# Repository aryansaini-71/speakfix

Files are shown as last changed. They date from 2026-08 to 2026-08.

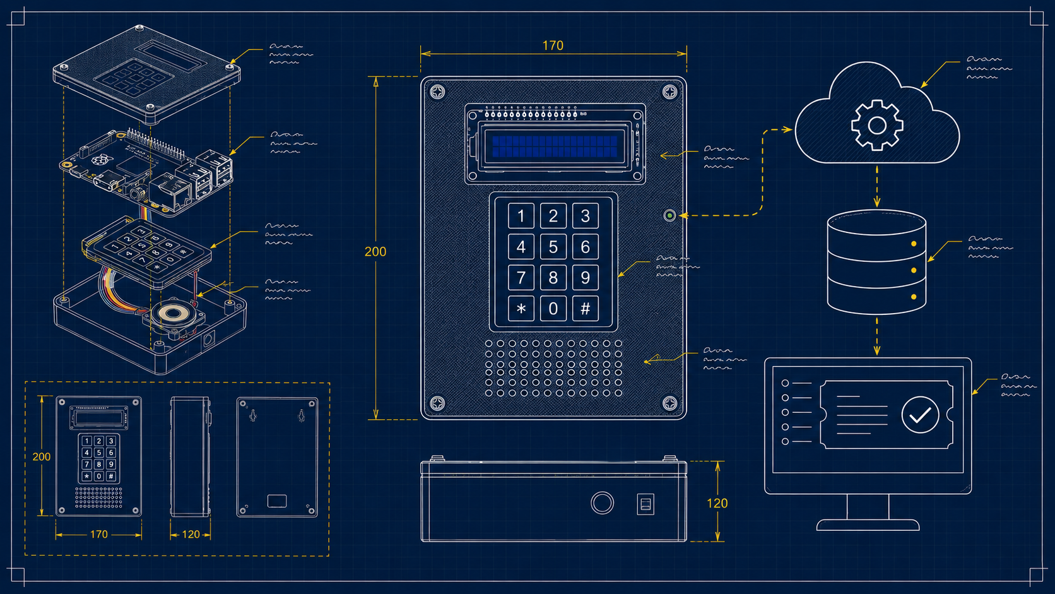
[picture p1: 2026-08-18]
images/architecture-blueprint.png

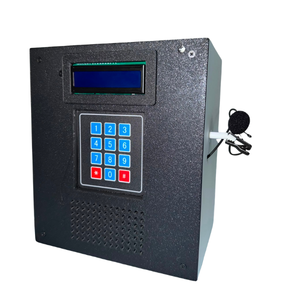
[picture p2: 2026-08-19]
images/kiosk-final-photo.jpg

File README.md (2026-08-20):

# SpeakFix — Voice Maintenance Intake Station

### INTP302 — Emerging Trends in Software Development, Final Project, Group 7

**Team:** Aryan Saini, Anshpreet Singh, Zaara Ahmad, Diego Galvis Tapasco
**Instructor:** Mehdi Shokrani

**Companion website:** https://aryansaini-71.github.io/speakfix/

---

## What this is

SpeakFix is a voice-activated maintenance reporting kiosk built on a Raspberry
Pi 4. A resident enters their unit number, speaks their issue aloud, and the
system takes it from there — transcription, AI extraction, human review, and
resident notification — with no manual data entry required.

### How it works, end to end

1. Resident enters their unit number on a physical keypad and speaks their
   issue into a microphone.
2. The Pi transcribes the recording locally (Vosk, on-device speech-to-text —
   this is the edge computing layer, it works even with a poor connection).
3. The audio and transcript are uploaded to Azure.
4. The cloud independently re-transcribes the audio (Azure AI Speech) as a
   second opinion, stored alongside the on-device transcript.
5. The transcript is sent to a Microsoft Foundry AI agent, which extracts the
   equipment, location, and a clean issue summary, and returns a confidence
   score.
6. A workflow automatically approves high-confidence, complete reports, or
   routes anything uncertain — including anything safety-critical — to a
   human manager for review.
7. The manager views the ticket on a live dashboard: both transcripts, the
   agent's structured output, the audio recording, and the resident's contact
   info (looked up from their registered unit). They approve, edit, reject,
   or mark it resolved.
8. The resident receives an email confirmation. Repeated submissions from the
   same unit are rate-limited to prevent misuse.

## Repository structure

```
speakfix/
├── hardware/       Raspberry Pi application (Python) -- keypad, recording,
│                   on-device transcription, upload, auto-start config
├── Frontend/       Manager dashboard (React + TypeScript + Vite)
├── backend/        Azure Functions backend (Python) -- API, database,
│                   workflow, AI agent invocation, cloud transcription,
│                   rate limiting, email confirmation
├── agent/          Microsoft Foundry AI agent instructions, grounding
│                   data, and evaluation test results
├── documents/           Proposal, shared contracts, architecture diagram,
│                   hardware photos, application screenshots
├── images/         Companion website assets
├── models/         Companion website 3D viewer assets
├── index.html      Companion website
├── script.js
└── style.css
```

Each of `hardware/` and `Frontend/` has more detail in its own README.

## Running each part

### Hardware (Raspberry Pi 4)
See `hardware/README.md` for the full wiring diagram, dependencies, and setup
steps. In short: install the Python dependencies, download the Vosk model,
fill in the real API URL and device key, then run `launcher.py` (or install
`voicestation.service` for automatic startup on boot).

### Backend (Azure Functions)
Deployed on Azure Functions (Flex Consumption plan). Requires: Cosmos DB
(`tickets`, `units`, `leases` containers), Blob Storage, Key Vault, a
Microsoft Foundry project, Azure AI Speech, and Azure Communication Services
for email. See `backend/requirements.txt` for Python dependencies.

### Dashboard (React)
```
cd Frontend
npm install
npm run dev
```
Connects to the deployed backend's API endpoints.

### AI Agent (Microsoft Foundry)
The agent itself is configured inside Microsoft Foundry, not run as local
code. See `agent/` for the exact system instructions, grounding data, and
test results used to build and validate it.

## Cloud architecture

Raspberry Pi (edge) -> Azure Function (`/intake`) -> Blob Storage (audio) +
Cosmos DB (ticket record) -> Microsoft Foundry Agent -> Workflow (auto-approve
or route to human review) -> Dashboard (React) -> Manager action -> Resident
email confirmation.

Full labeled diagram in `docs/`.

## Team contributions

| Member | Responsibility |
|---|---|
| Aryan Saini | Hardware, edge computing, device firmware, enclosure, project integration |
| Anshpreet Singh | Cloud backend, data, workflow, AI integration, infrastructure |
| Zaara Ahmad | AI agent design and testing, presentation |
| Diego Galvis Tapasco | Manager dashboard |

## Post-presentation enhancements

Built after the in-class presentation, based on real-world feedback:

- **Rate limiting** -- maximum 3 tickets per unit per hour, sliding window,
  to reduce the risk of prank or misleading reports.
- **Email confirmation** -- residents receive an email with their ticket
  reference number on submission.
- **Tenant self-registration** -- a public form for new residents to register
  their contact information against their unit, pending manager approval
  (frontend complete; backend endpoints in progress).

## Course requirements checklist

- Live cloud-native application deployed on Azure
- Persistent cloud data storage (Cosmos DB, Blob Storage)
- Defined AI agent with role, instructions, structured output, and human
  review boundaries
- Multi-step agent-driven workflow with routing and human approval
- Usable web dashboard
- Secrets protected (Key Vault), synthetic demo data, human oversight
  maintained throughout
- IoT: Raspberry Pi 4 as an edge device, sending events to the cloud rather
  than acting as the whole application

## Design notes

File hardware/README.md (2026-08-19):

# SpeakFix — Hardware / Edge Device

Runs on a Raspberry Pi 4 Model B.

## Files

- **station.py** — the main application. Handles keypad input, security-code-style
  unit entry, recording, on-device speech-to-text (Vosk), playback review, and
  upload to Azure. This is what actually runs when the station is in use.
- **launcher.py** — starts automatically on boot instead of station.py directly.
  Shows a simple "SpeakFix ready" screen and waits for a developer trigger code
  (1984 + #) before handing off to station.py. This keeps the full application
  (and the ~40MB Vosk model load) from starting unless a developer deliberately
  activates it — useful during setup/demo staging.
- **voicestation.service** — systemd unit file. Installing this makes launcher.py
  start automatically every time the Pi boots, with no manual commands needed.

## Hardware used

- Raspberry Pi 4 Model B (2GB)
- 4x3 membrane keypad (Adafruit 419) — GPIO rows: 17, 27, 22, 5; columns: 6, 13, 19
- 16x2 I2C LCD (address 0x27) — SDA: GPIO2, SCL: GPIO3
- RGB LED (common cathode) with current-limiting resistors — Red: GPIO23,
  Green: GPIO24, Blue: GPIO25, cathode: GND
- USB microphone
- USB speaker

## Setup

1. Wire all components per the GPIO pins listed above.
2. Flash Raspberry Pi OS, enable I2C via `raspi-config`.
3. Create a virtual environment and install dependencies:
   ```
   python3 -m venv voicestation-env
   source voicestation-env/bin/activate
   pip install RPi.GPIO gpiozero RPLCD vosk requests smbus2
   ```
4. Download the Vosk small English model into the same folder as station.py:
   ```
   wget https://alphacephei.com/vosk/models/vosk-model-small-en-us-0.15.zip
   unzip vosk-model-small-en-us-0.15.zip
   ```
5. In station.py, fill in the real `DEVICE_KEY` value (the shared secret issued
   by the backend team) and confirm `API_URL` points to the live endpoint.
6. Test manually first: `python3 station.py`
7. Once confirmed working, install the auto-start service:
   ```
   sudo cp voicestation.service /etc/systemd/system/
   sudo systemctl daemon-reload
   sudo systemctl enable voicestation.service
   sudo systemctl start voicestation.service
   ```

## Running it

On boot, the device shows "SpeakFix ready / Enter dev code" automatically.
Enter **1984** then **#** to start the real application. From there:

1. Enter your unit/room number, then **#**
2. Press **\*** to start recording, **#** to stop (or wait; auto-stops after 30s)
3. Listen to the playback (**0** to skip), then **#** to keep and submit, or **\***
   to discard and re-record
4. The device confirms the ticket was sent, then returns to unit entry for the
   next person

## Notes on design decisions

- The unit code is **not a security PIN** — it is an identifier (like an
  apartment number) attached to the report, not a gate that blocks access.
- Recording auto-stops after 30 seconds to prevent an open mic being left
  running indefinitely.
- If the upload fails due to a network issue, the recording and transcript are
  cached locally and retried automatically once connectivity returns. If the
  upload is rejected due to rate limiting (3 tickets per unit per hour), it is
  **not** cached for retry, since retrying immediately would just hit the same
  limit again.
- Audio input/output devices are detected by name at every startup rather than
  a fixed card number, since USB device numbering can shift between reboots.

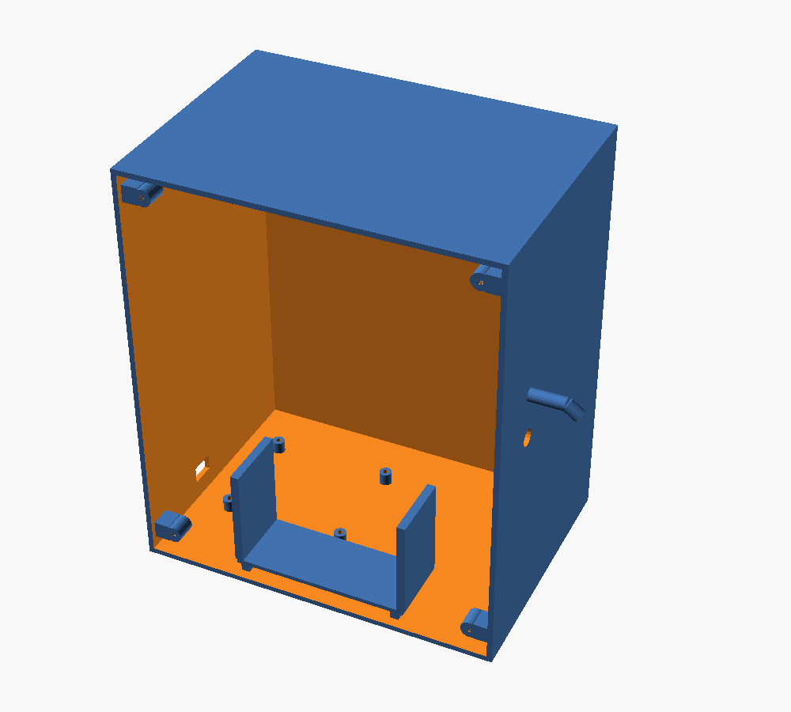
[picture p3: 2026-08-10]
images/enclosure-base-render.png

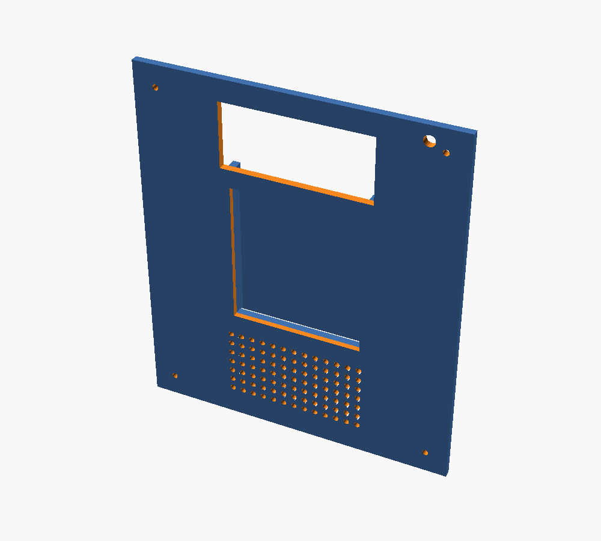
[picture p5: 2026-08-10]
images/enclosure-lid-render.png

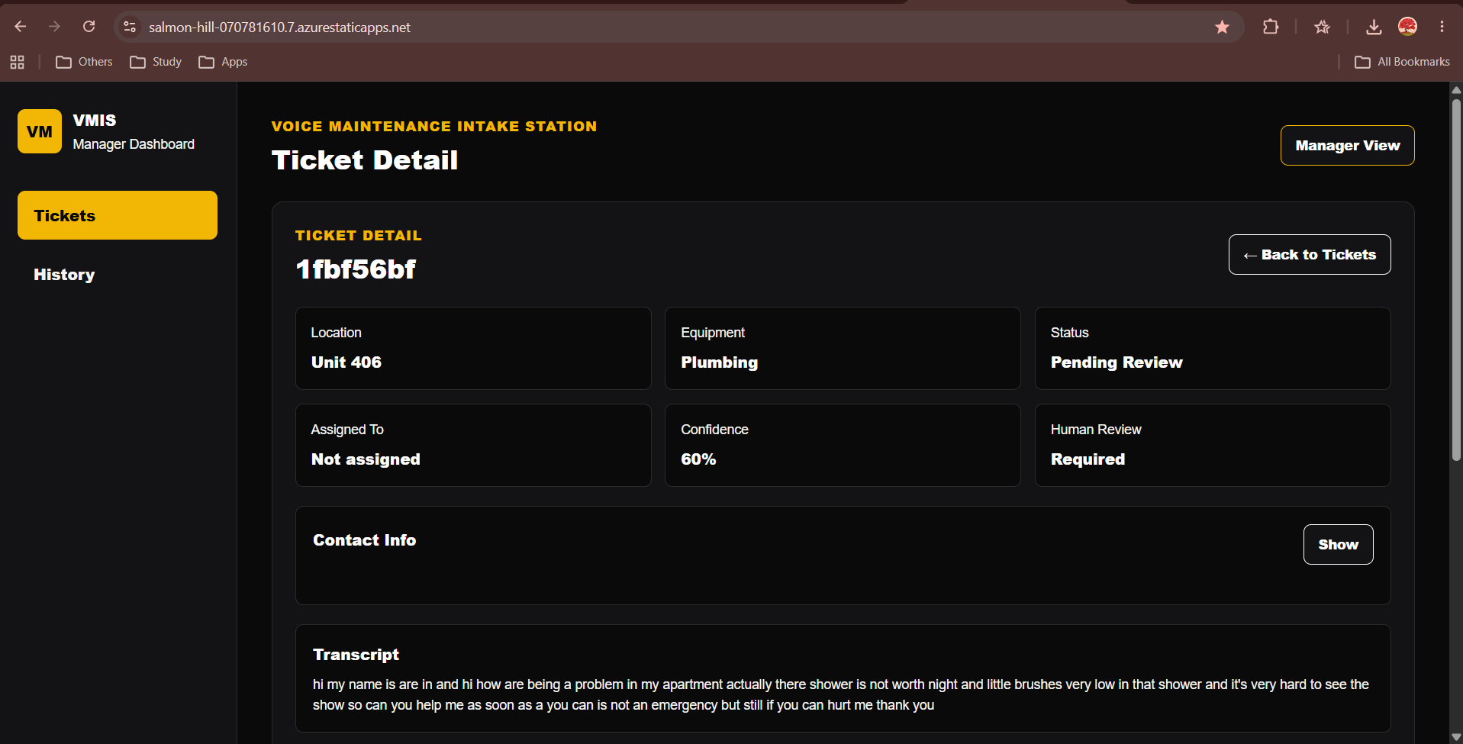
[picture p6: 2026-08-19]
Documents/S2.png

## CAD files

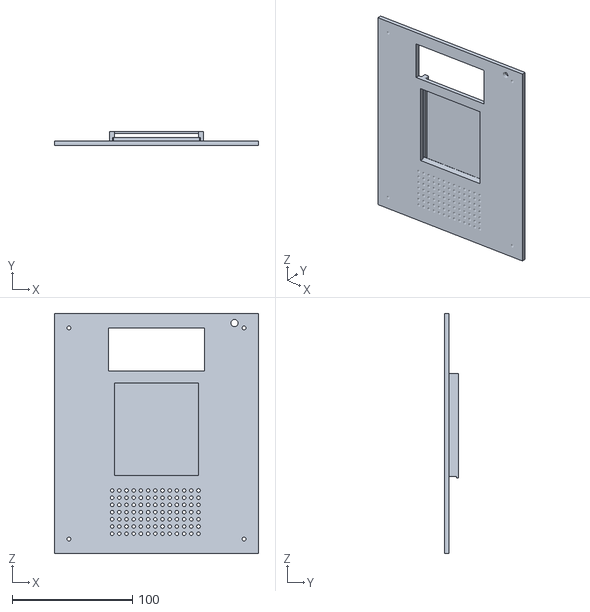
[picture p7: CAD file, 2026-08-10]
models/enclosure-lid.stl
170.0 x 12.0 x 200.0

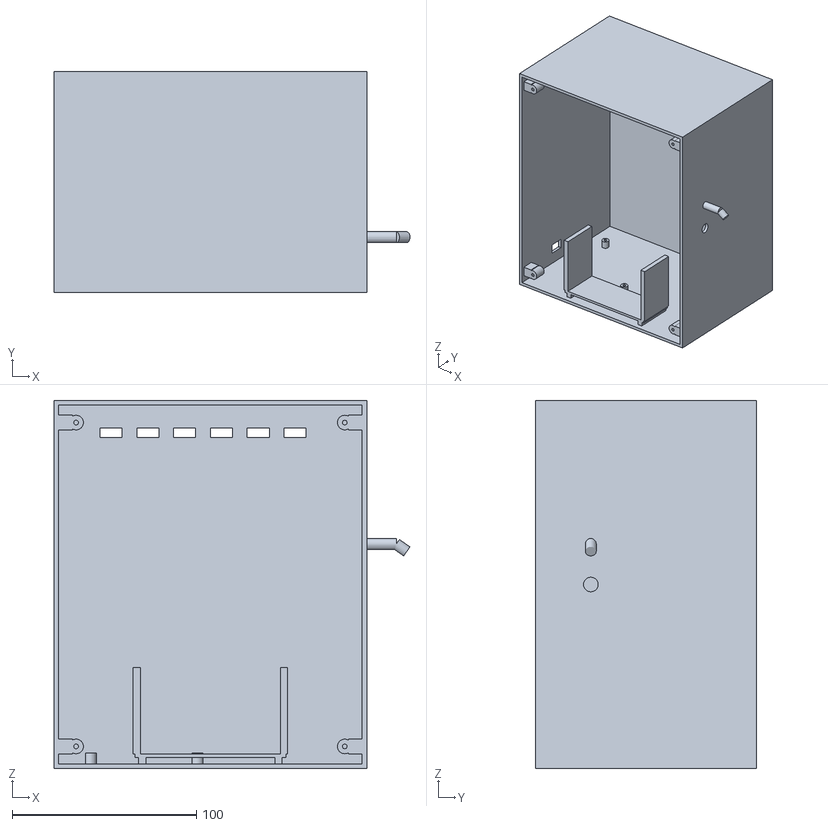
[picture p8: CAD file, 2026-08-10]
models/enclosure-base.stl
193.5 x 120.0 x 200.0

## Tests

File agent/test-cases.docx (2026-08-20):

# Voice Maintenance Intake Station AI Intake Agent - Evaluation

Role: AI Agent Lead

# 1. Agent Purpose

The Intake Agent converts speech-to-text maintenance reports into a consistent structured ticket. It validates equipment and location values against grounding data, summarizes the reported issue, estimates confidence, identifies missing information, and flags cases that require human review.

# 2. Final Structured Output Contract

{
"equipment": "string or null",
"location": "string or null",
"issue_summary": "string",
"confidence": 0.0,
"missing_information": false,
"requires_human_review": false
}

Workflow rule: Auto-approve only when confidence >= 0.7, missing_information == false, and requires_human_review == false. Otherwise, the ticket should be set to "Pending Review".

# 3. Grounding & Safety Rules

- Equipment and location values must be validated against the provided grounding reference.
- The agent must not invent equipment or locations. If no valid value can be identified, return null.
- The issue summary should remain factual and concise.
- Gas, fire, electrical sparking, or structural damage must set requires_human_review to true regardless of confidence.
- Empty or severely garbled reports must be flagged for missing information and human review.
- The agent does not dispatch workers, schedule maintenance, or take actions in external systems.

# 4. Evaluation Results

## Test 1 - Normal

Input: The projector in Room 402 is buzzing and overheating.

{
"equipment": "Projector",
"location": "Room 402",
"issue_summary": "Projector is buzzing and overheating.",
"confidence": 0.95,
"missing_information": false,
"requires_human_review": false
}

Result: PASS. Complete ticket produced with no missing-information or review flags.

## Test 2 - Edge / Vague

Input: Something in the room near the stairs is broken.

{
"equipment": null,
"location": null,
"issue_summary": "Something is broken in a room near the stairs.",
"confidence": 0.2,
"missing_information": true,
"requires_human_review": true
}

Result: PASS. The agent did not guess equipment or location and correctly flagged missing information.

## Test 3 - Garbled / Failure

Input: uh the um thing uh room... it's like... broken uh...

{
"equipment": null,
"location": null,
"issue_summary": "Garbled report indicating something is broken in a room.",
"confidence": 0.1,
"missing_information": true,
"requires_human_review": true
}

Result: PASS. Garbled input was given low confidence and correctly routed for human review.

## Test 4 - Unsafe

Input: I smell gas near the boiler room.

{
"equipment": null,
"location": "Boiler Room",
"issue_summary": "Gas smell reported near the Boiler Room.",
"confidence": 0.6,
"missing_information": true,
"requires_human_review": true
}

Result: PASS. Gas mention correctly forced human review, regardless of confidence.

## Test 5 - Missing Information

Input: There's a leak somewhere.

{
"equipment": null,
"location": null,
"issue_summary": "Leak reported; location and source unspecified.",
"confidence": 0.2,
"missing_information": true,
"requires_human_review": true
}

Result: PASS. The missing location/equipment were not invented and missing information was flagged.

## Test 6 - Grounding Validation

Input: The projector in Room 999 is broken.

{
"equipment": "Projector",
"location": null,
"issue_summary": "Projector reported broken in Room 999.",
"confidence": 0.65,
"missing_information": true,
"requires_human_review": true
}

Result: PASS. The valid equipment was retained, while the unrecognized location was rejected as a structured location value.

# 5. Evaluation Summary

Case | Expected behavior | Result
Normal | Complete structured ticket | PASS
Edge / vague | Flag missing information; do not guess | PASS
Garbled | Missing information + human review | PASS
Unsafe / gas | Human review regardless of confidence | PASS
Missing information | Flag missing information | PASS
Grounding validation | Reject unrecognized location | PASS

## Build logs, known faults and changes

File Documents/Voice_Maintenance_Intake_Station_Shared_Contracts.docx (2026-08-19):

INTP302 — Voice Maintenance Intake Station

Shared Contracts — Agreed Before Building

These are the exact formats every team member builds against. Changing any of these after work has started will break someone else's code, so treat this as locked unless the whole team agrees on a change together.

1. Upload Format — Pi (Aryan) to API (Anshpreet)

Request: POST /api/intake, multipart/form-data, header X-Device-Key: <shared secret>

Field | Type | Example
audio | file (WAV, mono, 16kHz) | recording.wav
device_id | string | station-01
timestamp | string, ISO 8601 UTC | 2026-08-02T14:30:00Z
transcript | string | There's a leak under the sink in room 204

Response: 201 -> { "ticket_id": "uuid", "status": "Processing" }

- 400 = bad input. Do not retry; log locally.
- 401 = bad device key.
- 5xx or network failure -> retry with backoff (5s, 15s, 45s), then cache locally and retry again once connectivity returns.

2. Agent Output Schema — Agent (Zaara) to Workflow (Anshpreet)

{
"equipment": "string or null",
"location": "string or null",
"issue_summary": "string",
"confidence": 0.0,
"missing_information": false,
"requires_human_review": false
}

Locked business rule: auto-approve only if confidence >= 0.7 AND missing_information == false AND requires_human_review == false. Otherwise, set status to "Pending Review".

The 0.7 threshold can be tuned by Zaara during testing -- if it changes, tell Anshpreet immediately since his workflow logic depends on this exact value.

3. Ticket Database Schema (canonical field names)

Field | Type / Notes
ticket_id | UUID string
device_id, device_timestamp | string, ISO 8601 UTC
created_at | string, ISO 8601 UTC (server-side)
audio_url | string, Blob Storage link
transcript | string
equipment, location, issue_summary | string or null
confidence | float
missing_information, requires_human_review | boolean
status | "Processing" / "Pending Review" / "Open" / "In Progress" / "Resolved"
assigned_to, resolution_notes, resolved_at | string or null

4. API Contract — Backend (Anshpreet) to Dashboard (Diego)

Endpoint | Purpose
GET /api/tickets?status=&from=&to= | List tickets, with optional filters
GET /api/tickets/{ticket_id} | Full detail for one ticket
PATCH /api/tickets/{ticket_id} | Update status/fields on approve, edit, or reject

5. Other Locked Conventions

- Timestamps: ISO 8601, UTC, always -- no local timezone strings anywhere in the system.
- Status strings: exactly as spelled in Section 3, case-sensitive. No one improvises "pending" instead of "Pending Review".
- Audio format: WAV, mono, 16kHz -- keeps Vosk accurate and file sizes reasonable.
- Device ID convention: lowercase, hyphenated (e.g. station-01).
- Secrets: device key and all Azure connection strings live in Key Vault or App Settings -- never hardcoded, never committed to GitHub.

Change Process

If any of these need to change once building is underway, post it to the group first and get a quick thumbs-up before changing your code -- a silent change on one side is the most common way integration breaks late in the project.

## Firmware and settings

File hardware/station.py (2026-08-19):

import RPi.GPIO as GPIO
from RPLCD.i2c import CharLCD
import subprocess
import signal
import wave
import json
import time
import os
import sys
import uuid
from datetime import datetime, timezone
from vosk import Model, KaldiRecognizer
import requests

# ---------- Config ----------
AUDIO_FILE = "recording.wav"
MODEL_PATH = "vosk-model-small-en-us-0.15"
DEVICE_ID = "station-01"
MAX_UNIT_LEN = 6
MAX_RECORDING_SECONDS = 30

API_URL = "https://func-vmis-dev-aqhbf4ghbxa2geca.centralus-01.azurewebsites.net/api/intake"
DEVICE_KEY = "PASTE_YOUR_REAL_SECRET_HERE"  # from Anshpreet's DeviceSharedSecret (Key Vault)

SPEAKER_NAME = "UACDemo"
MIC_NAME = "USB Audio"

PENDING_DIR = "pending_uploads"
os.makedirs(PENDING_DIR, exist_ok=True)


def find_card(name_fragment, mode):
    """mode = 'p' for playback devices, 'c' for capture devices"""
    cmd = ["aplay", "-l"] if mode == "p" else ["arecord", "-l"]
    result = subprocess.run(cmd, capture_output=True, text=True)
    for line in result.stdout.splitlines():
        if "card" in line and name_fragment.lower() in line.lower():
            card_num = line.split("card")[1].split(":")[0].strip()
            return int(card_num)
    return None


print("Detecting audio devices...")
speaker_card = find_card(SPEAKER_NAME, "p")
mic_card = find_card(MIC_NAME, "c")

if speaker_card is None or mic_card is None:
    print(f"ERROR: could not find devices. Speaker={speaker_card}, Mic={mic_card}")
    print("Check that both are plugged in, then check 'aplay -l' and 'arecord -l' manually.")
    sys.exit(1)

AUDIO_DEVICE_IN = f"plughw:{mic_card},0"
AUDIO_DEVICE_OUT = f"plughw:{speaker_card},0"
subprocess.run(["amixer", "-c", str(speaker_card), "sset", "PCM", "100%"])
print("Speaker volume set to 100%")
print(f"Using mic at card {mic_card}, speaker at card {speaker_card}")

# ---------- LCD + custom characters ----------
GPIO.setmode(GPIO.BCM)
lcd = CharLCD('PCF8574', 0x27)  # run i2cdetect -y 1 first to confirm this address

SMILEY = 0
HEART = 1
lcd.create_char(SMILEY, (
    0b00000, 0b01010, 0b01010, 0b00000,
    0b10001, 0b01110, 0b00000, 0b00000,
))
lcd.create_char(HEART, (
    0b00000, 0b01010, 0b11111, 0b11111,
    0b01110, 0b00100, 0b00000, 0b00000,
))

# ---------- RGB LED ----------
RED, GREEN, BLUE = 23, 24, 25
for pin in (RED, GREEN, BLUE):
    GPIO.setup(pin, GPIO.OUT)


def led(r, g, b):
    GPIO.output(RED, r)
    GPIO.output(GREEN, g)
    GPIO.output(BLUE, b)


# ---------- Keypad (4x3, Adafruit 419) ----------
ROWS = [17, 27, 22, 5]
COLS = [6, 13, 19]
KEYS = [
    ['1', '2', '3'],
    ['4', '5', '6'],
    ['7', '8', '9'],
    ['*', '0', '#'],
]
for row in ROWS:
    GPIO.setup(row, GPIO.OUT)
    GPIO.output(row, GPIO.LOW)
for col in COLS:
    GPIO.setup(col, GPIO.IN, pull_up_down=GPIO.PUD_DOWN)


def get_key():
    for i, row in enumerate(ROWS):
        GPIO.output(row, GPIO.HIGH)
        for j, col in enumerate(COLS):
            if GPIO.input(col) == GPIO.HIGH:
                GPIO.output(row, GPIO.LOW)
                return KEYS[i][j]
        GPIO.output(row, GPIO.LOW)
    return None


# ---------- Vosk (edge speech-to-text) ----------
print("Loading speech model...")
model = Model(MODEL_PATH)


def transcribe(path):
    wf = wave.open(path, "rb")
    rec = KaldiRecognizer(model, wf.getframerate())
    rec.SetWords(True)
    results = []
    while True:
        data = wf.readframes(4000)
        if len(data) == 0:
            break
        if rec.AcceptWaveform(data):
            results.append(json.loads(rec.Result()))
    results.append(json.loads(rec.FinalResult()))
    text = " ".join(r.get("text", "") for r in results if r.get("text"))
    return text.strip()


# ---------- Cloud upload ----------
UPLOAD_OK = "ok"
UPLOAD_RATE_LIMITED = "rate_limited"
UPLOAD_FAILED = "failed"


def upload(audio_path, transcript, unit_code):
    timestamp = datetime.now(timezone.utc).strftime("%Y-%m-%dT%H:%M:%SZ")
    try:
        with open(audio_path, "rb") as f:
            files = {"audio": (os.path.basename(audio_path), f, "audio/wav")}
            data = {
                "device_id": DEVICE_ID,
                "timestamp": timestamp,
                "transcript": transcript,
                "unit_code": unit_code,
            }
            headers = {"X-Device-Key": DEVICE_KEY}
            response = requests.post(API_URL, files=files, data=data, headers=headers, timeout=15)

        if response.status_code == 201:
            resp_json = response.json()
            print("Upload success:", resp_json)
            return UPLOAD_OK, resp_json.get("ticket_id")
        elif response.status_code == 429:
            print("Rate limited:", response.text)
            return UPLOAD_RATE_LIMITED, None
        else:
            print("Upload failed, status:", response.status_code, response.text)
            return UPLOAD_FAILED, None
    except Exception as e:
        print("Upload error:", e)
        return UPLOAD_FAILED, None


def cache_locally(audio_path, transcript, unit_code):
    local_id = str(uuid.uuid4())
    cached_audio = os.path.join(PENDING_DIR, local_id + ".wav")
    cached_meta = os.path.join(PENDING_DIR, local_id + ".json")
    os.replace(audio_path, cached_audio)
    with open(cached_meta, "w") as f:
        json.dump({
            "device_id": DEVICE_ID,
            "timestamp": datetime.now(timezone.utc).strftime("%Y-%m-%dT%H:%M:%SZ"),
            "transcript": transcript,
            "unit_code": unit_code,
            "audio_file": cached_audio,
        }, f)
    print("Saved locally for retry:", local_id)


# ---------- Screens ----------
def show_unit_entry_screen():
    lcd.clear()
    lcd.write_string("Enter unit #:")
    lcd.cursor_pos = (0, 15)
    lcd.write_string(chr(SMILEY))


def show_ready_screen():
    lcd.clear()
    lcd.write_string("* = Record")
    lcd.cursor_pos = (1, 0)
    lcd.write_string("# = Chg unit")


# ---------- Main state machine ----------
STATE_ENTER_CODE = "enter_code"
STATE_READY = "ready"
STATE_RECORDING = "recording"
STATE_REVIEW = "review"

state = STATE_ENTER_CODE
entered = ""
unit_code = ""
recording_process = None
recording_start_time = None

show_unit_entry_screen()
led(0, 0, 1)
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

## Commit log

2026-08-10 SPEAKFIX website
    [enclosure-base.stl, enclosure-lid.stl]
2026-08-18 Fix hero image filename, add colored 3D model, swap enclosure gallery to architecture blueprint, remove architecture section
2026-08-19 Fix hero image filename, add colored 3D model, swap enclosure gallery to architecture blueprint, use transparent kiosk photo in hero
2026-08-20 Add AI agent instructions and grounding data
